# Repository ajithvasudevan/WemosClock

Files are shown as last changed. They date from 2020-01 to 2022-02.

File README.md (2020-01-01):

## Wemos Clock

This clock is based on the Wemos D1 Mini MCU and it keeps accurate time using NTP servers over the internet, just like regular computers.

### Schematic Diagram
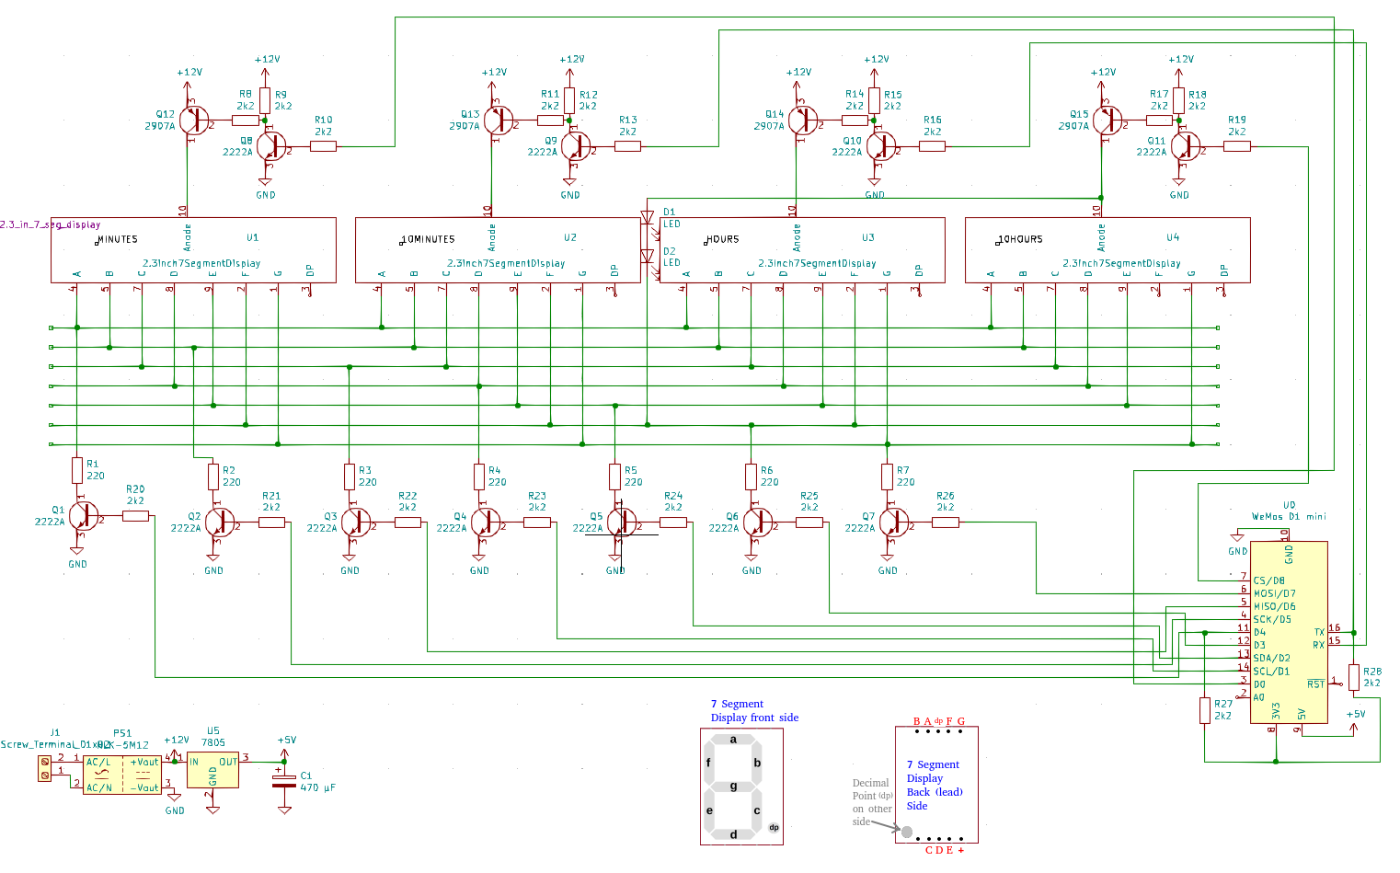
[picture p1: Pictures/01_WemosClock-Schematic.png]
Schematic Diagram


### Parts List
1. 7-Segment Display units (2.3 inch high for this PCB design, otherwise, could be any size) - 4 Nos
2. Wemos D1 Mini - 1 No
3. General purpose NPN transistors (E.g., 2N 2222A)  - 11 Nos
4. General purpose PNP transistors (E.g., 2N 2907A)  - 4 Nos
5. Resistors - 2k2 Ω   - 21 Nos
6. Resistors - 220 Ω   -  7 Nos
7. 12V DC 5W Power supply module HLK-5M12 - 1 No
8. 5V Regulator IC 7805 - 1 No
9. Capacitor 470 μF  - No
10. PCB fabricated to the specifications [here](KiCAD/WemosClock.kicad_pcb)

### PCB
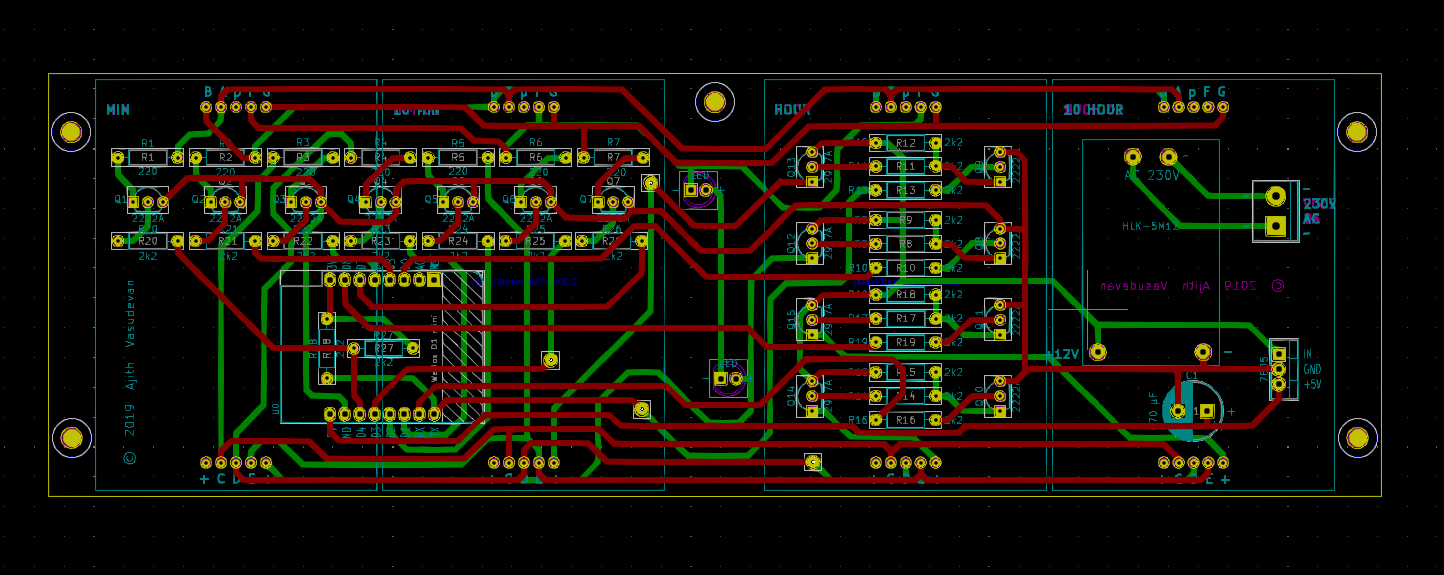
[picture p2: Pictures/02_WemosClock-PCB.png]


### PCB (3-D Model - component side)
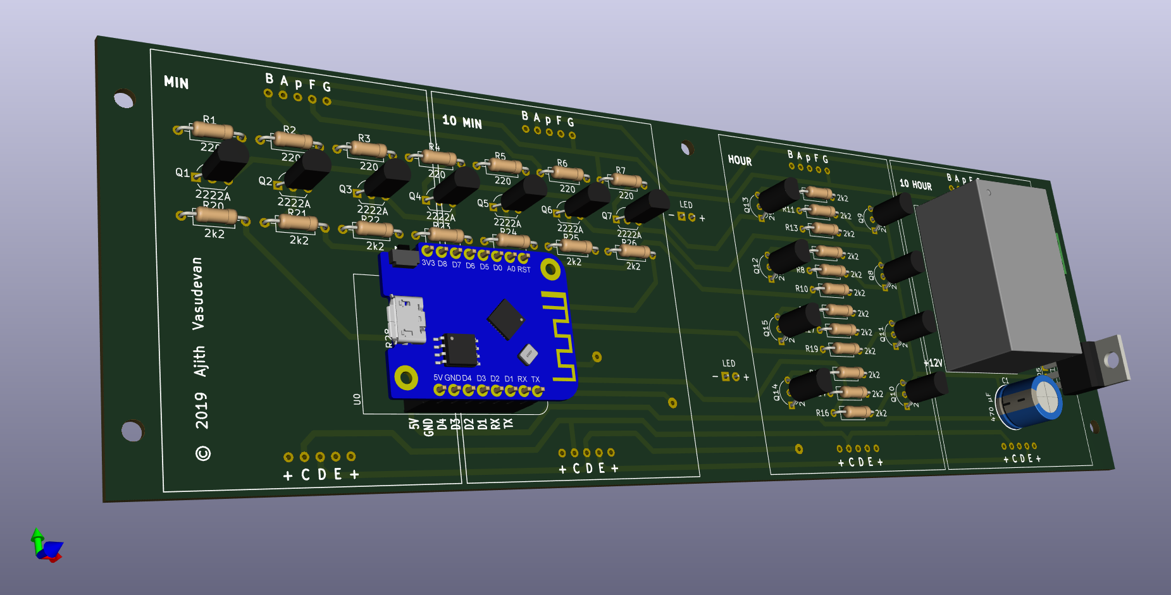
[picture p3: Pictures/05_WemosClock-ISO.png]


### PCB (3-D Model - display side)
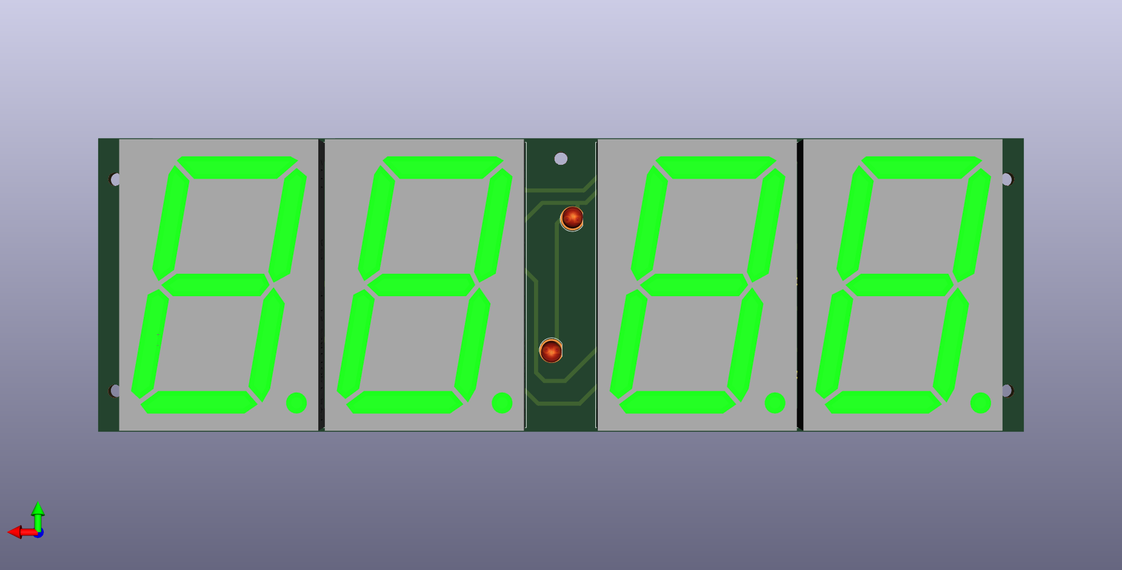
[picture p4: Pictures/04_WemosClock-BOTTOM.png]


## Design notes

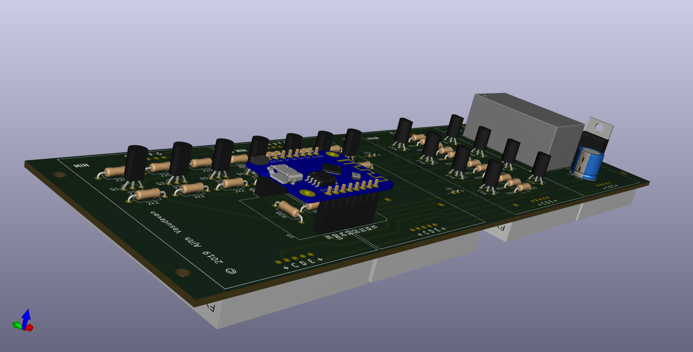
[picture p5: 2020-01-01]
Pictures/07_WemosClock-ISO2.png

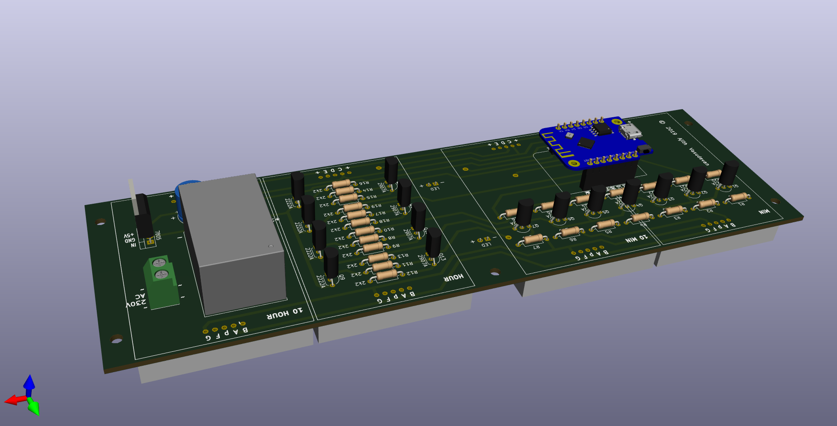
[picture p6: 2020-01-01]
Pictures/06_WemosClock-ISO1.png

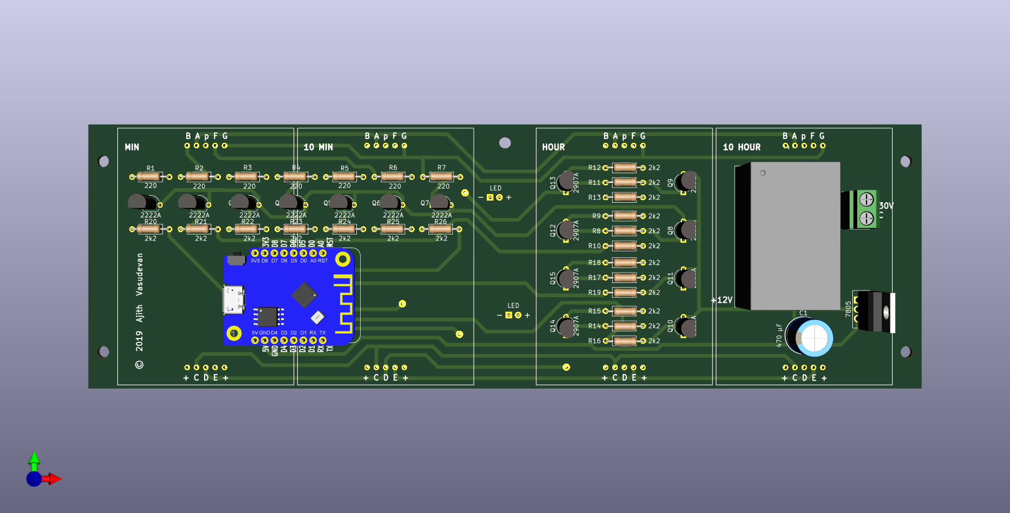
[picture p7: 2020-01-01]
Pictures/03_WemosClock-TOP.png

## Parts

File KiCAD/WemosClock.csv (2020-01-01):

Reference | Value | Footprint | Datasheet
U2 | 2.3inch7SegmentDisplay | WemosClock:2.3_in_7_seg_display
U3 | 2.3inch7SegmentDisplay | WemosClock:2.3_in_7_seg_display
U4 | 2.3inch7SegmentDisplay | WemosClock:2.3_in_7_seg_display
Q12 | 2907A | Package_TO_SOT_THT:TO-92L_Inline_Wide | ~
Q8 | 2222A | Package_TO_SOT_THT:TO-92L_Inline_Wide | ~
R8 | 2k2 | Resistor_THT:R_Axial_DIN0207_L6.3mm_D2.5mm_P10.16mm_Horizontal | ~
R10 | 2k2 | Resistor_THT:R_Axial_DIN0207_L6.3mm_D2.5mm_P10.16mm_Horizontal | ~
R9 | 2k2 | Resistor_THT:R_Axial_DIN0207_L6.3mm_D2.5mm_P10.16mm_Horizontal | ~
Q13 | 2907A | Package_TO_SOT_THT:TO-92L_Inline_Wide | ~
Q9 | 2222A | Package_TO_SOT_THT:TO-92L_Inline_Wide | ~
R11 | 2k2 | Resistor_THT:R_Axial_DIN0207_L6.3mm_D2.5mm_P10.16mm_Horizontal | ~
R13 | 2k2 | Resistor_THT:R_Axial_DIN0207_L6.3mm_D2.5mm_P10.16mm_Horizontal | ~
R12 | 2k2 | Resistor_THT:R_Axial_DIN0207_L6.3mm_D2.5mm_P10.16mm_Horizontal | ~
Q14 | 2907A | Package_TO_SOT_THT:TO-92L_Inline_Wide | ~
Q10 | 2222A | Package_TO_SOT_THT:TO-92L_Inline_Wide | ~
R14 | 2k2 | Resistor_THT:R_Axial_DIN0207_L6.3mm_D2.5mm_P10.16mm_Horizontal | ~
R16 | 2k2 | Resistor_THT:R_Axial_DIN0207_L6.3mm_D2.5mm_P10.16mm_Horizontal | ~
R15 | 2k2 | Resistor_THT:R_Axial_DIN0207_L6.3mm_D2.5mm_P10.16mm_Horizontal | ~
Q15 | 2907A | Package_TO_SOT_THT:TO-92L_Inline_Wide | ~
Q11 | 2222A | Package_TO_SOT_THT:TO-92L_Inline_Wide | ~
R17 | 2k2 | Resistor_THT:R_Axial_DIN0207_L6.3mm_D2.5mm_P10.16mm_Horizontal | ~
R19 | 2k2 | Resistor_THT:R_Axial_DIN0207_L6.3mm_D2.5mm_P10.16mm_Horizontal | ~
R18 | 2k2 | Resistor_THT:R_Axial_DIN0207_L6.3mm_D2.5mm_P10.16mm_Horizontal | ~
R25 | 2k2 | Resistor_THT:R_Axial_DIN0207_L6.3mm_D2.5mm_P10.16mm_Horizontal | ~
Q2 | 2222A | Package_TO_SOT_THT:TO-92L_Inline_Wide | ~
R21 | 2k2 | Resistor_THT:R_Axial_DIN0207_L6.3mm_D2.5mm_P10.16mm_Horizontal | ~
R2 | 220 | Resistor_THT:R_Axial_DIN0207_L6.3mm_D2.5mm_P10.16mm_Horizontal | ~
Q7 | 2222A | Package_TO_SOT_THT:TO-92L_Inline_Wide | ~
R26 | 2k2 | Resistor_THT:R_Axial_DIN0207_L6.3mm_D2.5mm_P10.16mm_Horizontal | ~
R7 | 220 | Resistor_THT:R_Axial_DIN0207_L6.3mm_D2.5mm_P10.16mm_Horizontal | ~
Q1 | 2222A | Package_TO_SOT_THT:TO-92L_Inline_Wide | ~
R20 | 2k2 | Resistor_THT:R_Axial_DIN0207_L6.3mm_D2.5mm_P10.16mm_Horizontal | ~
R1 | 220 | Resistor_THT:R_Axial_DIN0207_L6.3mm_D2.5mm_P10.16mm_Horizontal | ~
Q6 | 2222A | Package_TO_SOT_THT:TO-92L_Inline_Wide | ~
R6 | 220 | Resistor_THT:R_Axial_DIN0207_L6.3mm_D2.5mm_P10.16mm_Horizontal | ~
R24 | 2k2 | Resistor_THT:R_Axial_DIN0207_L6.3mm_D2.5mm_P10.16mm_Horizontal | ~
Q5 | 2222A | Package_TO_SOT_THT:TO-92L_Inline_Wide | ~
R5 | 220 | Resistor_THT:R_Axial_DIN0207_L6.3mm_D2.5mm_P10.16mm_Horizontal | ~
R23 | 2k2 | Resistor_THT:R_Axial_DIN0207_L6.3mm_D2.5mm_P10.16mm_Horizontal | ~
Q4 | 2222A | Package_TO_SOT_THT:TO-92L_Inline_Wide | ~
R4 | 220 | Resistor_THT:R_Axial_DIN0207_L6.3mm_D2.5mm_P10.16mm_Horizontal | ~
R22 | 2k2 | Resistor_THT:R_Axial_DIN0207_L6.3mm_D2.5mm_P10.16mm_Horizontal | ~
Q3 | 2222A | Package_TO_SOT_THT:TO-92L_Inline_Wide | ~
R3 | 220 | Resistor_THT:R_Axial_DIN0207_L6.3mm_D2.5mm_P10.16mm_Horizontal | ~
D1 | LED | LED_THT:LED_D5.0mm | ~
D2 | LED | LED_THT:LED_D5.0mm | ~
U0 | WeMos D1 mini | WemosClock:WEMOS_D1_mini_3.0.0 | https://wiki.wemos.cc/products:d1:d1_mini#documentation
R27 | 2k2 | Resistor_THT:R_Axial_DIN0207_L6.3mm_D2.5mm_P10.16mm_Horizontal | ~
R28 | 2k2 | Resistor_THT:R_Axial_DIN0207_L6.3mm_D2.5mm_P10.16mm_Horizontal | ~
U1 | 2.3inch7SegmentDisplay | WemosClock:2.3_in_7_seg_display
U5 | 7805 | Package_TO_SOT_THT:TO-220-3_Vertical | http://www.st.com/content/ccc/resource/technical/document/datasheet/41/4f/b3/b0/12/d4/47/88/CD00000444.pdf/files/CD00000444.pdf/jcr:content/translations/en.CD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
C1 | 470 μF | Capacitor_THT:CP_Radial_D10.0mm_P5.00mm | ~
J1 | Screw_Terminal_01x02 | WemosClock:TerminalBlock_bornier-2_P5.08mm | ~
PS1 | HLK-5M12 | WemosClock:HLK-5M12 | http://www.hlktech.net/product_detail.php?ProId=54

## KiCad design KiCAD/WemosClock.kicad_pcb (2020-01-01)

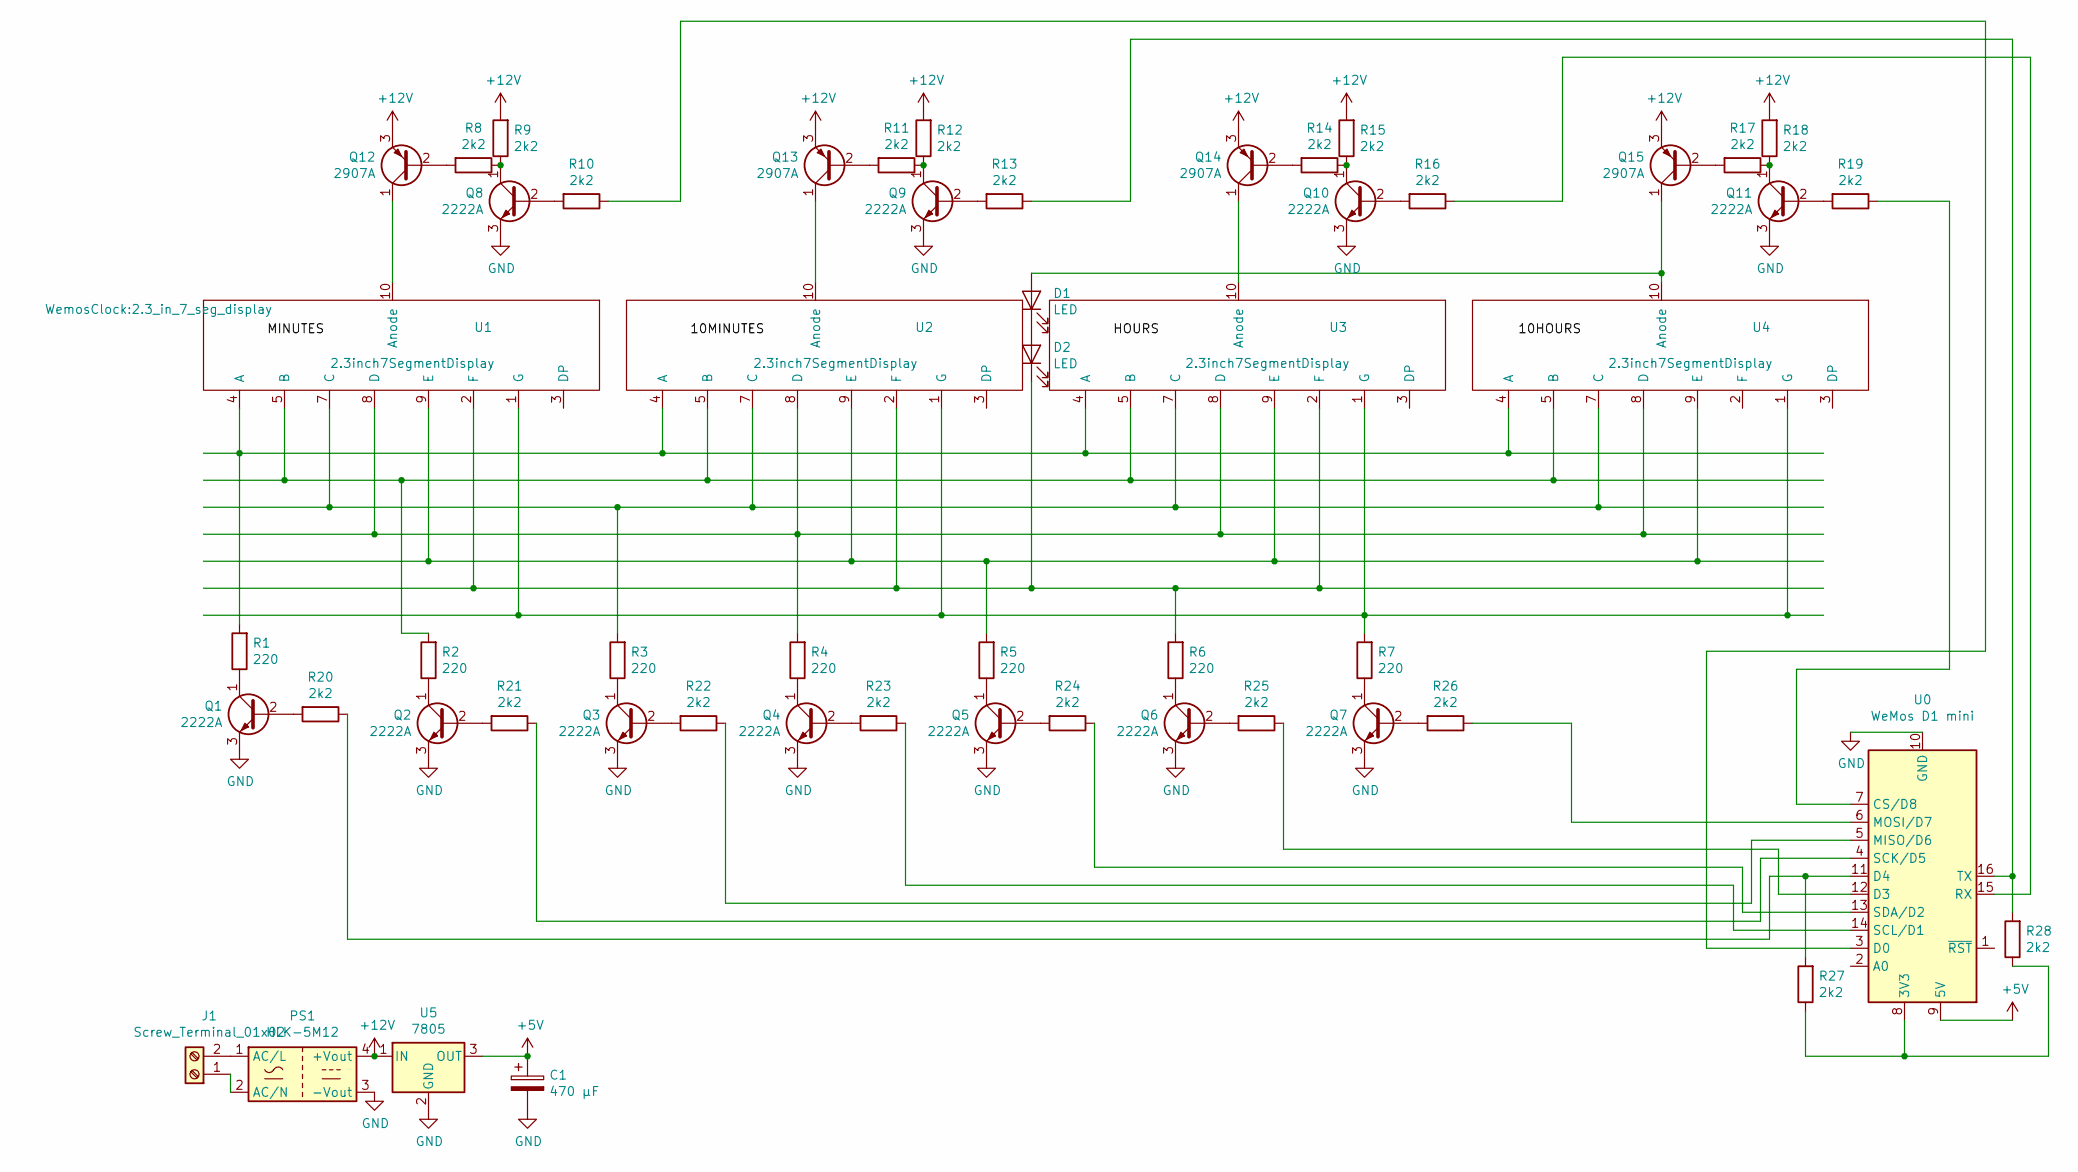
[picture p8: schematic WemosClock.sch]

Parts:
C1: 470 μF; CP_Radial_D10.0mm_P5.00mm
D1, D2: LED; LED_D5.0mm
J1: Screw_Terminal_01x02; TerminalBlock_bornier-2_P5.08mm
PS1: HLK-5M12
Q1, Q2, Q3, Q4, Q5, Q6, Q7, Q8, Q9, Q10, Q11: 2222A; TO-92L_Inline_Wide
Q12, Q13, Q14, Q15: 2907A; TO-92L_Inline_Wide
R1, R2, R3, R4, R5, R6, R7: 220; R_Axial_DIN0207_L6.3mm_D2.5mm_P10.16mm_Horizontal
R8, R9, R10, R11, R12, R13, R14, R15, R16, R17, R18, R19, R20, R21, R22, R23, R24, R25, R26, R27, R28: 2k2; R_Axial_DIN0207_L6.3mm_D2.5mm_P10.16mm_Horizontal
U0: WeMos D1 mini; WEMOS_D1_mini_3.0.0
U1, U2, U3, U4: 2.3inch7SegmentDisplay; 2.3_in_7_seg_display
U5: 7805; TO-220-3_Vertical

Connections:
+5V: C1.1, U0.9 (5V), U5.3 (OUT)
+12V: PS1.4 (+Vout), Q12.3 (E), Q13.3 (E), Q14.3 (E), Q15.3 (E), R9.2, R12.2, R15.2, R18.2, U5.1 (IN)
GND: C1.2, PS1.3 (-Vout), Q1.3 (E), Q2.3 (E), Q3.3 (E), Q4.3 (E), Q5.3 (E), Q6.3 (E), Q7.3 (E), Q8.3 (E), Q9.3 (E), Q10.3 (E), Q11.3 (E), U0.10 (GND), U5.2 (GND)
unnamed: D1.1 (K), D2.2 (A)
unnamed: D1.2 (A), Q15.1 (C), U4.10 (Anode)
unnamed: D2.1 (K), R6.2, U1.2 (F), U2.2 (F), U3.2 (F)
unnamed: J1.1, PS1.2 (AC/N)
unnamed: J1.2, PS1.1 (AC/L)
unnamed: Q1.1 (C), R1.1
unnamed: Q1.2 (B), R20.2
unnamed: Q2.1 (C), R2.1
unnamed: Q2.2 (B), R21.2
unnamed: Q3.1 (C), R3.1
unnamed: Q3.2 (B), R22.2
unnamed: Q4.1 (C), R4.1
unnamed: Q4.2 (B), R23.2
unnamed: Q5.1 (C), R5.1
unnamed: Q5.2 (B), R24.2
unnamed: Q6.1 (C), R6.1
unnamed: Q6.2 (B), R25.2
unnamed: Q7.1 (C), R7.1
unnamed: Q7.2 (B), R26.2
unnamed: Q8.1 (C), R8.1, R9.1
unnamed: Q8.2 (B), R10.2
unnamed: Q9.1 (C), R11.1, R12.1
unnamed: Q9.2 (B), R13.2
unnamed: Q10.1 (C), R14.1, R15.1
unnamed: Q10.2 (B), R16.2
unnamed: Q11.1 (C), R17.1, R18.1
unnamed: Q11.2 (B), R19.2
unnamed: Q12.1 (C), U1.10 (Anode)
unnamed: Q12.2 (B), R8.2
unnamed: Q13.1 (C), U2.10 (Anode)
unnamed: Q13.2 (B), R11.2
unnamed: Q14.1 (C), U3.10 (Anode)
unnamed: Q14.2 (B), R14.2
unnamed: Q15.2 (B), R17.2
unnamed: R1.2, U1.4 (A), U2.4 (A), U3.4 (A), U4.4 (A)
unnamed: R2.2, U1.5 (B), U2.5 (B), U3.5 (B), U4.5 (B)
unnamed: R3.2, U1.7 (C), U2.7 (C), U3.7 (C), U4.7 (C)
unnamed: R4.2, U1.8 (D), U2.8 (D), U3.8 (D), U4.8 (D)
unnamed: R5.2, U1.9 (E), U2.9 (E), U3.9 (E), U4.9 (E)
unnamed: R7.2, U1.1 (G), U2.1 (G), U3.1 (G), U4.1 (G)
unnamed: R10.1, U0.3 (D0)
unnamed: R13.1, R28.2, U0.16 (TX)
unnamed: R16.1, U0.15 (RX)
unnamed: R19.1, U0.7 (CS/D8)
unnamed: R20.1, R27.2, U0.11 (D4)
unnamed: R21.1, U0.4 (SCK/D5)
unnamed: R22.1, U0.5 (MISO/D6)
unnamed: R23.1, U0.14 (SCL/D1)
unnamed: R24.1, U0.13 (SDA/D2)
unnamed: R25.1, U0.12 (D3)
unnamed: R26.1, U0.6 (MOSI/D7)
unnamed: R27.1, R28.1, U0.8 (3V3)

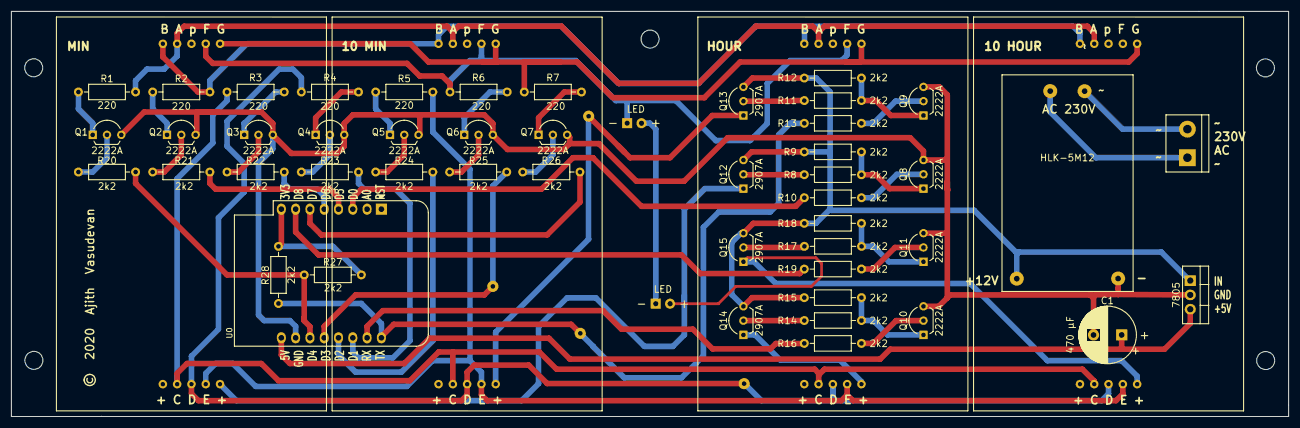
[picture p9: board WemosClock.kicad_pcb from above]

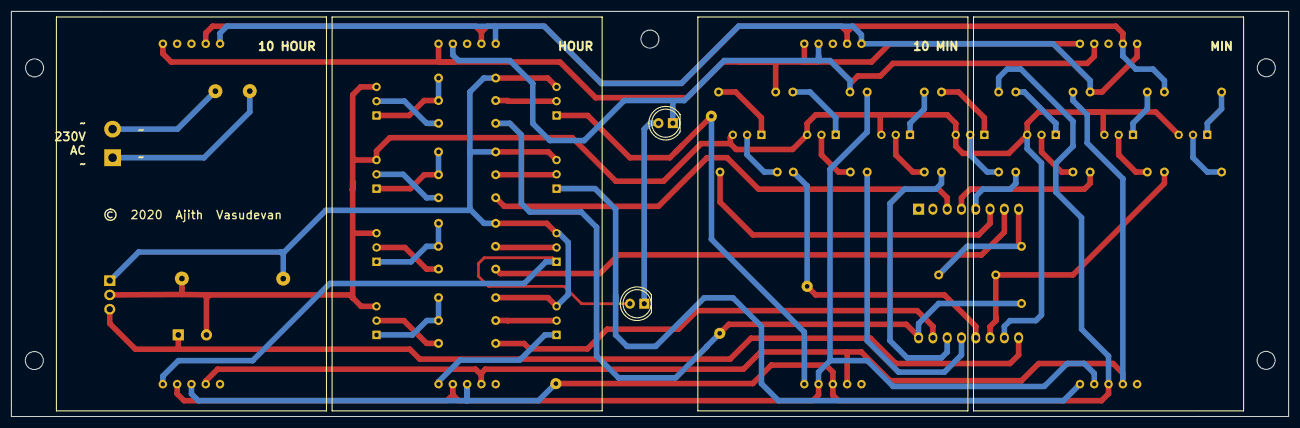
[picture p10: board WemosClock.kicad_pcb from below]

Board: 2 copper layers, 227.0 x 72.0 mm, 54 parts (6 on the bottom side), 55 nets.

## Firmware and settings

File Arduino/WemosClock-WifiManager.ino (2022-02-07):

#include <NTPClient.h>
#include <ESP8266WiFi.h>
#include <WiFiUdp.h>
#include <WiFiManager.h> // https://github.com/tzapu/WiFiManager

WiFiUDP ntpUDP;
//NTPClient timeClient(ntpUDP, "asia.pool.ntp.org", 5.5 * 3600, 60 * 60000);
NTPClient timeClient(ntpUDP, "time.cloudflare.com", 5.5 * 3600, 60 * 60000);     // Use any accessible internet time-server

bool updated = false;
int sc = 0, hr = 12, mt = 34;
int baseDelay = 2000;


const char *clockName = "AjithsClock";        // Set the name of the WiFiManager SSID as well 
                                              // as the Title displayed in the WiFiManager Web UI

const int numeral[10] = {
   //ABCDEFG /dp
   B11111100, // 0
   B01100000, // 1
   B11011010, // 2
   B11110010, // 3
   B01100110, // 4
   B10110110, // 5
   B10111110, // 6
   B11100000, // 7
   B11111110, // 8
   B11110110, // 9
};
const int Tx = 1;   // 10 Min
const int Rx = 3;   // 1  Hr

                         // dp G  F  E  D  C  B  A     
const int segmentPins[] = { D7,D7,D3,D2,D1,D6,D5,D4 };
const int nbrDigits= 4; // the number of digits in the LED display

                                // 1m  10m 1h  10h
const int digitPins[nbrDigits] = { D0, Tx, Rx, D8 };


bool shouldSaveConfig = false;

void saveConfigCallback () {
  shouldSaveConfig = true;
}


void setup() {
  WiFiManager wm;
  wm.setShowInfoErase(true);
  wm.setTitle("Setup WiFi Connection");
  wm.setHostname(clockName);
  wm.setWiFiAutoReconnect(true); 
  //wm.resetSettings();
  wm.setSaveConfigCallback(saveConfigCallback);
  wm.setConfigPortalTimeout(180);
  wm.setConnectTimeout(10);
  wm.setConnectRetries(2);
  wm.setSaveConnectTimeout(10);

  if (!wm.autoConnect(clockName, "")) {    // can set a password here for WiFiManager AP
    delay(3000);
    ESP.restart();
    delay(5000);
  }

  pinMode(Tx, FUNCTION_3); // Setting TX to GPIO
  pinMode(Rx, FUNCTION_3); // Setting RX to GPIO


  timeClient.begin();
  delay(1000);

  while ( !updated ) {
    updated = timeClient.forceUpdate();
    if(!updated ) delay ( 2000 );
  }
  updated = false;  
  
  for(int i=0; i < 8; i++) {
    pinMode(segmentPins[i], OUTPUT); 
  }
  for(int i=0; i < nbrDigits; i++) {
    pinMode(digitPins[i], OUTPUT);
  }

}


void loop() {
  hr = timeClient.getHours();
  mt = timeClient.getMinutes();
  sc = timeClient.getSeconds();
  
  if ((hr == 3) && mt == 0 && !updated) {
    timeClient.update();
    updated = true;
  }
  if(mt > 0) updated = false;

  if(hr > 12) {
    hr = hr - 12;
  }
  if(hr == 0) hr = 12;
  
  int value = hr * 100 + mt;
   
  showNumber(value);
//  delay(3);
} 
 
void showNumber( int number)
{
  // display the value corresponding to each digit
  // leftmost digit is 0, rightmost is one less than the number of places
  for( int digit = 0; digit <nbrDigits; digit++)  {

      showDigit( number % 10, digit) ;
      number = number / 10;

  }
} 
 
// Displays given number on a 7-segment display at the given digit position
void showDigit( int number, int digit)
{
  digitalWrite( digitPins[digit], LOW );
  if(digit == 3) {

    for(int segment = 1; segment < 8; segment++)  {
      if (segment == 2) {
      
        if(millis() % 1000 < 500) digitalWrite( segmentPins[segment], 1);
        else digitalWrite( segmentPins[segment], 0);
      }
      else digitalWrite( segmentPins[segment], 0);
    }
    
    if(number == 0) {
      digitalWrite( digitPins[digit], HIGH );
      delayMicroseconds(baseDelay); 
      digitalWrite( digitPins[digit], LOW );
      return;
    }
  }

  
  for(int segment = 1; segment < 8; segment++)  {
    boolean isBitSet = bitRead(numeral[number], segment);
    if(!(digit == 3 && segment == 2)) digitalWrite( segmentPins[segment], isBitSet);
  }
   
  digitalWrite( digitPins[digit], HIGH );
  delayMicroseconds(baseDelay); 
  digitalWrite( digitPins[digit], LOW );
}

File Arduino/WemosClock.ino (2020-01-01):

#include <TimeLib.h>
#include <NtpClientLib.h>
#include <ESP8266WiFi.h>

#define YOUR_WIFI_SSID "<YOUR_SSID>"
#define YOUR_WIFI_PASSWD "<YOUR_PASSWORD>"

#define NTP_TIMEOUT 1500

int8_t timeZone = 5;
int8_t minutesTimeZone = 30;
const PROGMEM char *ntpServer = "asia.pool.ntp.org";
bool wifiFirstConnected = false;

String timeString;
bool updated = true;
int sc = 0, hr = 12, mt = 34, cln = 0;

// For GREEN 7-Segment Displays
//int baseDelay = 1000;
//const int OFF_FACTOR = 2;

// For BLUE 7-Segment Displays
int baseDelay = 1000;
const int OFF_FACTOR = 0;

// For RED 7-Segment Displays
//int baseDelay = 1000;
//const int OFF_FACTOR = 1;


const int numeral[10] = {
   //ABCDEFG /dp
   B11111100, // 0
   B01100000, // 1
   B11011010, // 2
   B11110010, // 3
   B01100110, // 4
   B10110110, // 5
   B10111110, // 6
   B11100000, // 7
   B11111110, // 8
   B11110110, // 9
};
const int Tx = 1;   // 10 Min
const int Rx = 3;   // 1  Hr

                         // dp G  F  E  D  C  B  A     
const int segmentPins[] = { D7,D7,D3,D2,D1,D6,D5,D4 };
const int nbrDigits= 4; // the number of digits in the LED display

                                // 1m  10m 1h  10h
const int digitPins[nbrDigits] = { D0, Tx, Rx, D8 };



void onSTAConnected (WiFiEventStationModeConnected ipInfo) {
    //Serial.printf ("Connected to %s\r\n", ipInfo.ssid.c_str ());
}


// Start NTP only after IP network is connected
void onSTAGotIP (WiFiEventStationModeGotIP ipInfo) {
    wifiFirstConnected = true;
}

// Manage network disconnection
void onSTADisconnected (WiFiEventStationModeDisconnected event_info) {
    WiFi.reconnect ();
}

void processSyncEvent (NTPSyncEvent_t ntpEvent) {
    if (ntpEvent < 0) {
        Serial.printf ("Time Sync error: %d\n", ntpEvent);
        if (ntpEvent == noResponse)
            Serial.println ("NTP server not reachable");
        else if (ntpEvent == invalidAddress)
            Serial.println ("Invalid NTP server address");
        else if (ntpEvent == errorSending)
            Serial.println ("Error sending request");
        else if (ntpEvent == responseError)
            Serial.println ("NTP response error");
    } else {
        if (ntpEvent == timeSyncd) {
            Serial.print ("Got NTP time: ");
            Serial.println (NTP.getTimeDateString (NTP.getLastNTPSync ()));
        }
    }
}

boolean syncEventTriggered = false; // True if a time even has been triggered
NTPSyncEvent_t ntpEvent; // Last triggered event

void setup () {
    pinMode(Tx, FUNCTION_3); // TX to GPIO
    pinMode(Rx, FUNCTION_3); // RX to GPIO
    for(int i=0; i < 8; i++) {
      pinMode(segmentPins[i], OUTPUT); 
    }
    for(int i=0; i < nbrDigits; i++) {
      pinMode(digitPins[i], OUTPUT);
    }

  
    static WiFiEventHandler e1, e2, e3;

    WiFi.mode (WIFI_STA);
    WiFi.begin (YOUR_WIFI_SSID, YOUR_WIFI_PASSWD);

    NTP.onNTPSyncEvent ([](NTPSyncEvent_t event) {
        ntpEvent = event;
        syncEventTriggered = true;
    });

    e1 = WiFi.onStationModeGotIP (onSTAGotIP);// As soon WiFi is connected, start NTP Client
    e2 = WiFi.onStationModeDisconnected (onSTADisconnected);
    e3 = WiFi.onStationModeConnected (onSTAConnected);
}

void loop () {
    timeString = NTP.getTimeStr();
    int hr = timeString.substring(0, 2).toInt();
    int mt = timeString.substring(3, 5).toInt();
    int sc = timeString.substring(6, 8).toInt();

    if(mt > 0) updated = false;
  
    if(hr > 12) {
      hr = hr - 12;
    }
    if(hr == 0) hr = 12;
    
    int value = hr * 100 + mt;
     
    showNumber(value);

    if (wifiFirstConnected) {
        wifiFirstConnected = false;
        NTP.setInterval (63);
        NTP.setNTPTimeout (NTP_TIMEOUT);
        NTP.begin (ntpServer, timeZone, false, minutesTimeZone);
    }

}


void showNumber( int number)
{
  // display the value corresponding to each digit
  // leftmost digit is 0, rightmost is one less than the number of places
  for( int digit = 0; digit <nbrDigits; digit++)  {
      showDigit( number % 10, digit) ;
      number = number / 10;
  }
} 
 
// Displays given number on a 7-segment display at the given digit position
void showDigit( int number, int digit)
{
  digitalWrite( digitPins[digit], LOW );
  if(digit == 3) {
    
    for(int segment = 1; segment < 8; segment++)  {
      if((millis() % 1000)  < 500) cln = 0; else cln = 1;
      if (segment == 2) digitalWrite( segmentPins[segment], cln);
      else digitalWrite( segmentPins[segment], 0); 
    }
    
    if(number == 0) {
      digitalWrite( digitPins[digit], HIGH );
      delayMicroseconds(baseDelay); 
      digitalWrite( digitPins[digit], LOW );
      return;
    }
  }

  
  for(int segment = 1; segment < 8; segment++)  {
    boolean isBitSet = bitRead(numeral[number], segment);
    if(!(digit == 3 && segment == 2)) digitalWrite( segmentPins[segment], isBitSet);
  }
   
  digitalWrite( digitPins[digit], HIGH );
  delayMicroseconds(baseDelay); 
  digitalWrite( digitPins[digit], LOW );
  delayMicroseconds(OFF_FACTOR * baseDelay);
}

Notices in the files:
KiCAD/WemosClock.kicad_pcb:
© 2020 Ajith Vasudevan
